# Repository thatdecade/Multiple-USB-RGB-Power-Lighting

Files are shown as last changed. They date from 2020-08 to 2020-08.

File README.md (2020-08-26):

# Multiple USB RGB Power Lighting
The goal of this project is to set the color of two neopixel rings based on which USB cable is powered.  I plugged the USB cables into my game consoles, so when a console is powered, the shelf llght will have the corresponding color.

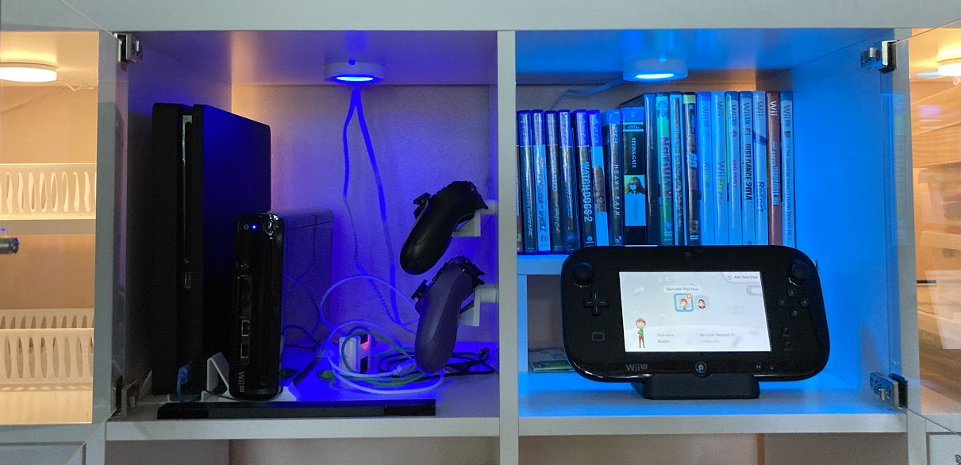
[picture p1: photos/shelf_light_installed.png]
Neopixel Ring Puck Lights


**How it Works**

Plug each USB cable into your separate devices.  The isolation diodes allow the trinket to be powered by any or all of the USB cables.  Periodically, the trinket will read the input pins to determine which USB cable is powered and will play the programmed animation and colors or combination of colors.

The trinket needs pull down resistors to set the idle state of an input pin when a USB cable is not powered or left unattached.

----

**Part List**

* Trinket 5V - <https://amzn.to/3gpQX6z>
* NeoPixel Ring - 16 RGB - <https://amzn.to/34wuUcn>
* Wired Under Cabinet Puck Lights - <https://amzn.to/2YssTdl>
* Backpack PCB - <https://oshpark.com/shared_projects/CATpwF4r>
* Three diodes - <https://octopart.com/search?q=CMF04%28TE12L%2CQ%2CM%29>
* Three 10k resistors - <https://octopart.com/search?q=RC0603FR-0710KL>
* Three USB Cables (dollar store)

The backpack pcb is optional.  You can just as easily wire up the diodes and resistors on a protoboard.  

**Pin Assignments**

Not all pins on the Trinket are equal.  Be sure to read Adafruit's help pages <https://learn.adafruit.com/introducing-trinket/pinouts>  Pins 3 and 4 should not be used as inputs and will conflict with talking to a PC for programming.

* GPIO #0 - Red Input, Attach to +5V wire from the first USB cable
* GPIO #1 - Blue Input, Attach to +5V wire from the second USB cable
* GPIO #2 - Green Input, Attach to +5V wire from the third USB cable
* GPIO #3 - Neopixel Data
* GPIO #4 - Potentiometer (optional)

I added a quick disconnect to Pin 4 so when I wanted to connect to the PC, I could remove the potentiometer without soldering.

**Assembly**

If you have access to a 3d printer, an enclosure stl is provided.  Thread the cables through the enclosure sides before soldering.

Solder the resistors and diodes to the backpack, then wire into the trinket.  Strip the USB cables and identify the 5V and Ground wires.  Use a multimeter to be sure, but the 5V and Ground wires can also be identified by thickness.  The power wires should be thicker than the data wires.

*There is a RGB LED and three 220 ohm resistors on the backback pcb for debugging, leave them unpopulated.*

Take apart the puck light and remove the PCB.  Recycling the wiring that came with the puck light to wire into your neopixel rings.  Use hot glue or epoxy to add the neopixel ring behind the puck light's diffuser.

**Programming**

Use the arduino ide and adafruit neopixel library and adafruit trinket board package.  Be sure to read Adafruit's help pages for each module.

* <https://learn.adafruit.com/adafruit-arduino-ide-setup/arduino-1-dot-6-x-ide>
* <https://learn.adafruit.com/introducing-trinket/setting-up-with-arduino-ide>
* <https://github.com/adafruit/Adafruit_NeoPixel>

If you followed my pin assignments, you can use the code without modification.  After you get the neopixels to light up and changing based on which USB cable is powered.   You can explore modifying the colors and animations.

**Usage, Testing, and Setting Colors**

After initial programming, when you plug in each of the three USB cables you should see the ring light up red or blue or green.  Combinations are allowed.

If you installed the optional potentiometer, you can change the color selected by a USB cable without reprogramming using a PC.  There are 16 colors preprogrammed to select from.

1. You will need two USB power ports to plug into.  
2. Connect the Micro USB on the trinket so power remains on while the other USBs are unplugged.  Leave this plugged in throughout these steps.
3. Take the USB cable you want to configure and plug it into your power block.  
4. Wait 5 seconds (or just wait for the animation to complete)
5. Rapidly unplug and plug the cable in four times, ending with the USB plugged in.
    1. You must complete this four times, before the spinning animation ends.
    2. If you do it right, the animations will stop and you will see a steady light.  
    3. If you mess up, wait 5 seconds before trying again.
6. Slowly rotate the potentiometer to select the color.
7. Unplug the USB cable to save the color selection.

----

**Additional Notes**

I used the NeoPixel ring and Trinket I listed above because that is what I had extra.  If I were to make one from scratch, I would use the [RGBW Neopixel Rings](https://octopart.com/search?q=adafruit+2854) and [Arduino NANO 33 IoT](https://amzn.to/3lg6Tfj) instead.  So I could use the Puck Light for normal lighting with commands to Alexa to change colors too!  

More Info: <https://blog.arduino.cc/2019/11/12/create-a-voice-controlled-device-with-alexa-and-arduino-iot-cloud-in-7-minutes/>

_We are a participant in the Amazon Services LLC Associates Program, an affiliate advertising program designed to provide a means for us to earn fees by linking to Amazon.com and affiliated sites._

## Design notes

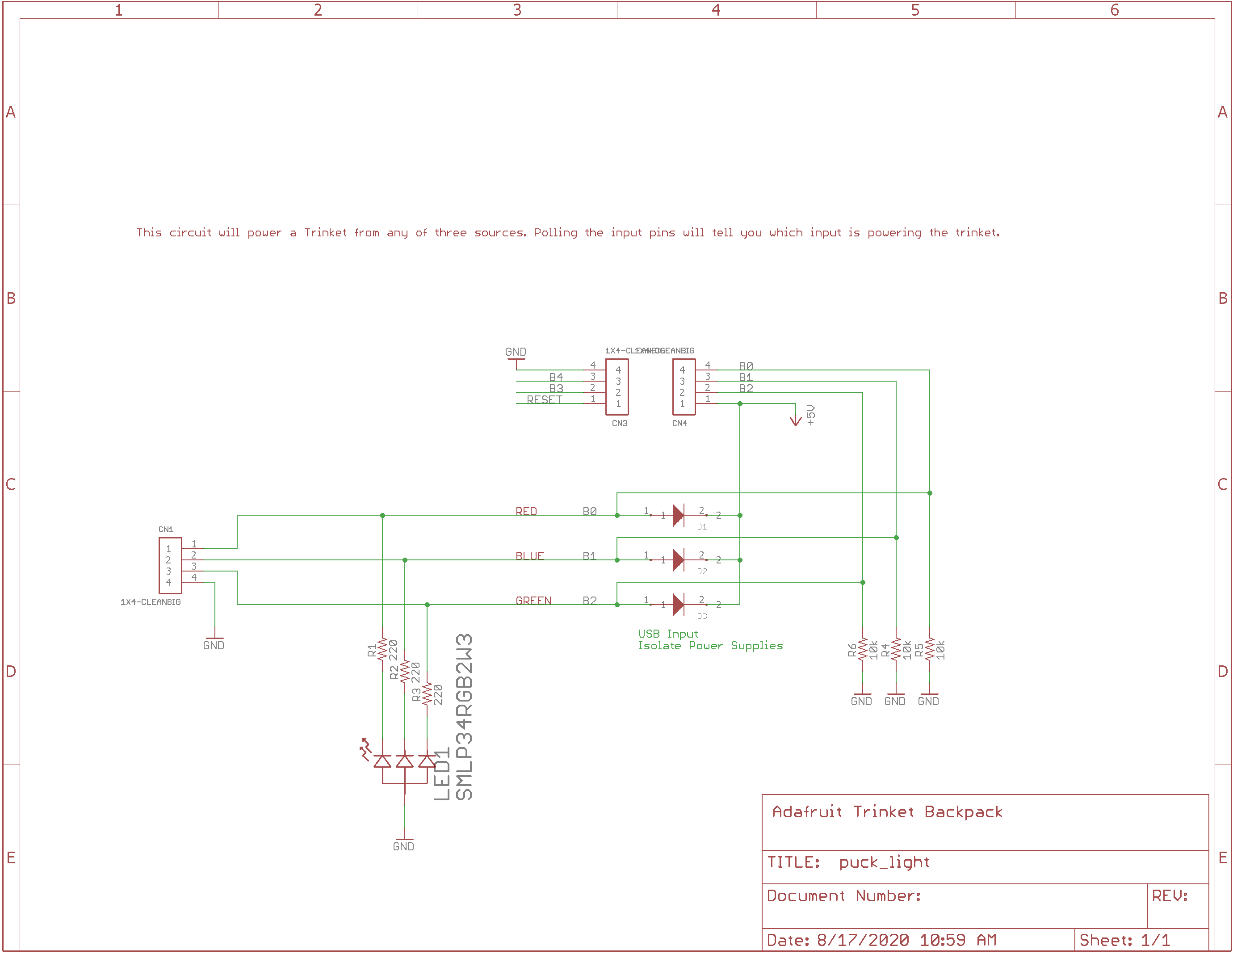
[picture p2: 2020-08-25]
pcb/schematic.png

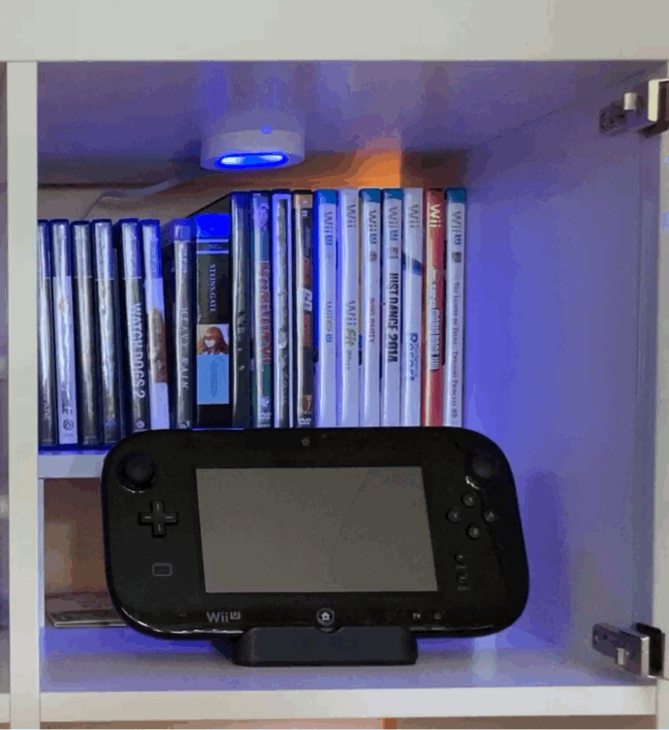
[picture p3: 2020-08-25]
photos/shelf_light_animation.gif

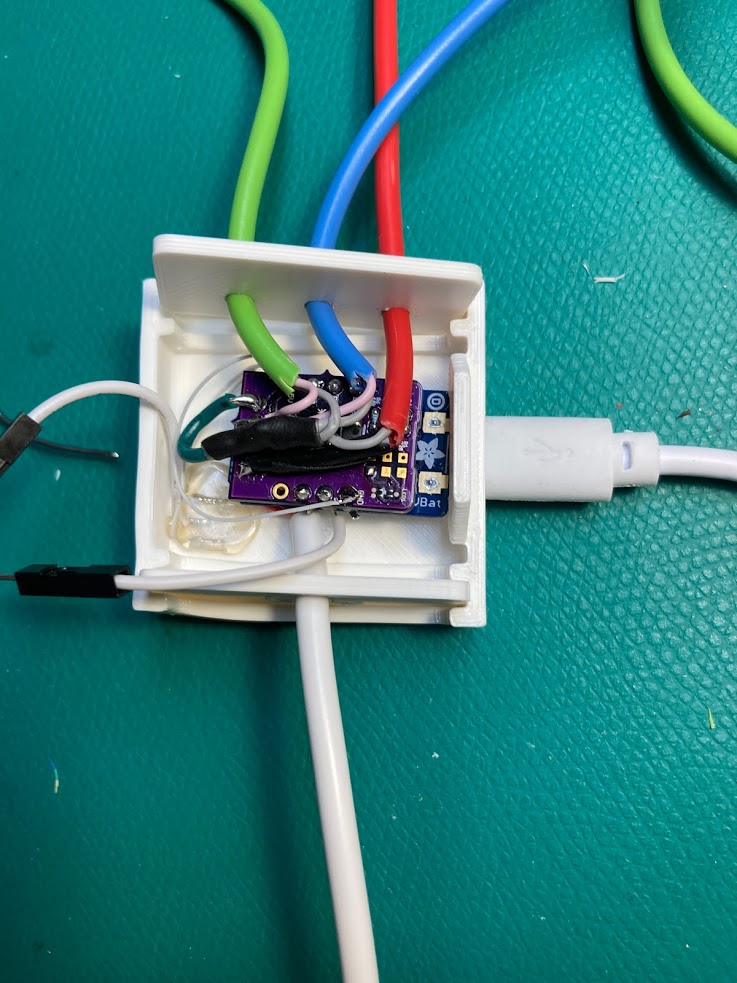
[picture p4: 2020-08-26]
photos/inside_enclosure.jpg

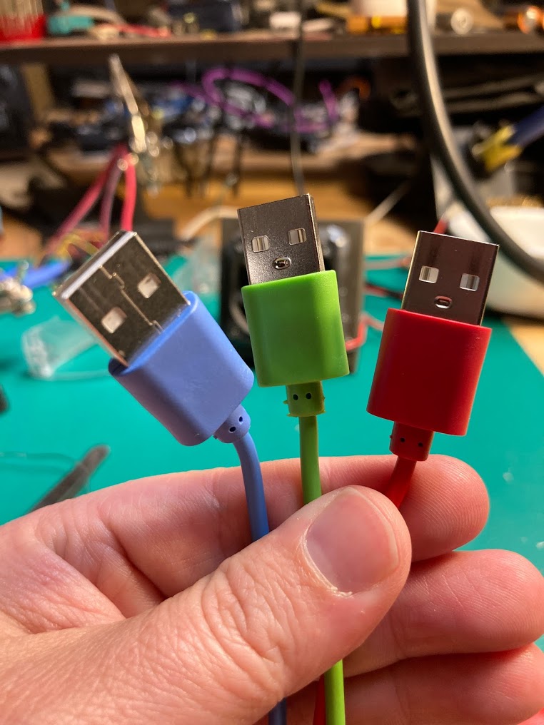
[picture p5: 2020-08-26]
photos/colored_usb_cables.jpg

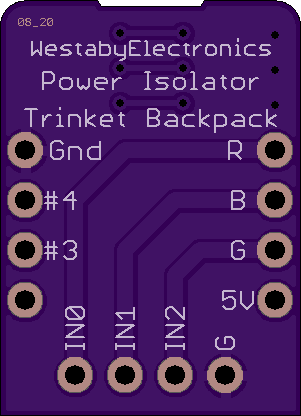
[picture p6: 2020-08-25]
photos/PCB_Front.png

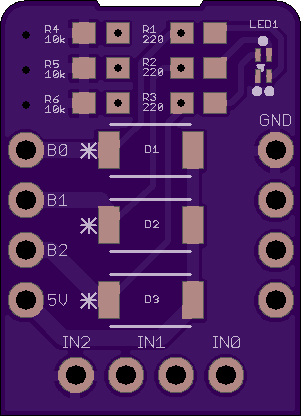
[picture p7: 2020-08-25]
photos/PCB_Back.png

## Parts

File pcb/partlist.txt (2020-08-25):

Partlist

EAGLE Version 7.7.0 Copyright (c) 1988-2016 CadSoft

Assembly variant: 

Part     Value            Package          Library            Position (inch)       Orientation

D1       CMF04(TE12L,Q,M) M-FLAT_TOS       CMF04(TE12L,Q)     (0.3 0.55)            MR0
D2       CMF04(TE12L,Q,M) M-FLAT_TOS       CMF04(TE12L,Q)     (0.3 0.4)             MR0
D3       CMF04(TE12L,Q,M) M-FLAT_TOS       CMF04(TE12L,Q)     (0.3 0.25)            MR0
LED1     SMLP34RGB2W3     LED_SML-P24M_ROM SMLP34RGB2W3A      (0.075 0.72)          MR90
R1       220              0603             SparkFun-Resistors (0.205 0.785)         MR180
R2       220              0603             SparkFun-Resistors (0.205 0.715)         MR180
R3       220              0603             SparkFun-Resistors (0.205 0.645)         MR180
R4       10k              0603             SparkFun-Resistors (0.4 0.715)           MR0
R5       10k              0603             SparkFun-Resistors (0.4 0.785)           MR0
R6       10k              0603             SparkFun-Resistors (0.4 0.645)           MR0

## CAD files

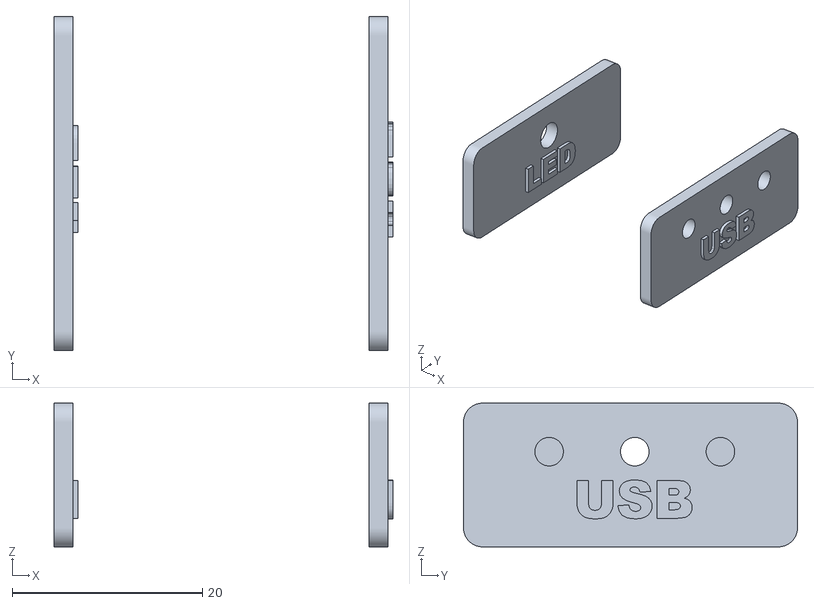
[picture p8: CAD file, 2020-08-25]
3d_parts/LED_USB_Box_Sides.stl
35.6 x 35.1 x 15.1

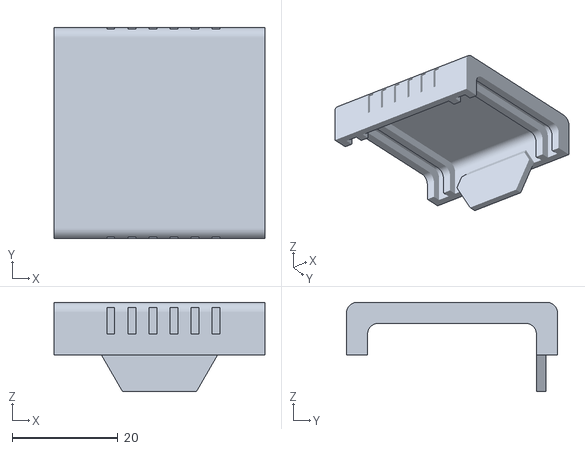
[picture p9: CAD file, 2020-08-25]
3d_parts/LED_USB_Box_Top.stl
40.0 x 40.0 x 16.9

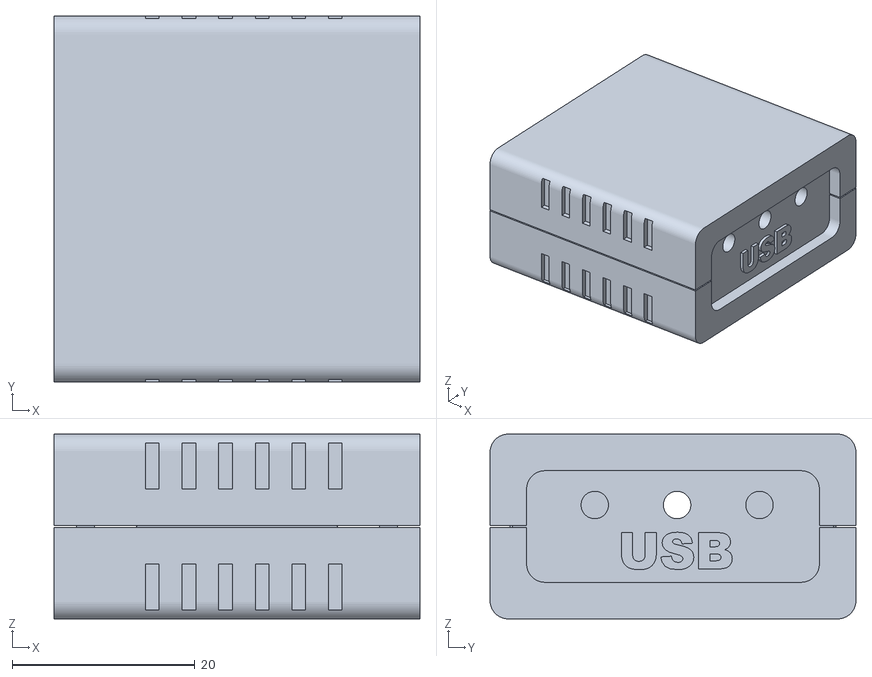
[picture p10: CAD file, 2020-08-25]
3d_parts/LED_USB_Box.stl
40.0 x 40.0 x 20.2

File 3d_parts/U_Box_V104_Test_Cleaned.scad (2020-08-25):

/*//////////////////////////////////////////////////////////////////
              -    FB Aka Heartman/Hearty 2016     -                   
              -   http://heartygfx.blogspot.com    -                  
              -       OpenScad Parametric Box      -                     
              -         CC BY-NC 3.0 License       -                      
////////////////////////////////////////////////////////////////////                                                                                                             
12/02/2016 - Fixed minor bug 
28/02/2016 - Added holes ventilation option                    
09/03/2016 - Added PCB feet support, fixed the shell artefact on export mode. 

*/////////////////////////// - Info - //////////////////////////////

// All coordinates are starting as integrated circuit pins.
// From the top view :

//   CoordD           <---       CoordC
//                                 ^
//                                 ^
//                                 ^
//   CoordA           --->       CoordB


////////////////////////////////////////////////////////////////////


////////// - Paramètres de la boite - Box parameters - /////////////

/* [Box dimensions] */
// - Longueur - Length  
  Length        = 40;       
// - Largeur - Width
  Width         = 40;                     
// - Hauteur - Height  
  Height        = 20;  
// - Epaisseur - Wall thickness  
  Thick         = 2;//[2:5]  
  
/* [Box options] */
// - Diamètre Coin arrondi - Filet diameter  
  Filet         = 2;//[0.1:12] 
// - lissage de l'arrondi - Filet smoothness  
  Resolution    = 50;//[1:100] 
// - Tolérance - Tolerance (Panel/rails gap)
  m             = 0.9;
// Pieds PCB - PCB feet (x4) 
  PCBFeet       = 0;// [0:No, 1:Yes]
// - Decorations to ventilation holes
  Vent          = 0;// [0:No, 1:Yes]
// - Decoration-Holes width (in mm)
  Vent_width    = 1.5;   


  
/* [PCB_Feet] */
//All dimensions are from the center foot axis

// - Coin bas gauche - Low left corner X position
PCBPosX         = 7;
// - Coin bas gauche - Low left corner Y position
PCBPosY         = 6;
// - Longueur PCB - PCB Length
PCBLength       = 70;
// - Largeur PCB - PCB Width
PCBWidth        = 50;
// - Heuteur pied - Feet height
FootHeight      = 10;
// - Diamètre pied - Foot diameter
FootDia         = 8;
// - Diamètre trou - Hole diameter
FootHole        = 3;  
  

/* [STL element to export] */
//Coque haut - Top shell
TShell          = 1;// [0:No, 1:Yes]
//Coque bas- Bottom shell
BShell          = 1;// [0:No, 1:Yes]
//Panneau avant - Front panel
FPanL           = 1;// [0:No, 1:Yes]
//Panneau arrière - Back panel  
BPanL           = 1;// [0:No, 1:Yes]


  
/* [Hidden] */
// - Couleur coque - Shell color  
Couleur1        = "Orange";       
// - Couleur panneaux - Panels color    
Couleur2        = "OrangeRed";    
// Thick X 2 - making decorations thicker if it is a vent to make sure they go through shell
Dec_Thick       = Vent ? Thick*2 : Thick; 
// - Depth decoration
Dec_size        = Vent ? Thick*2 : 0.8;





/////////// - Boitier générique bord arrondis - Generic rounded box - //////////

module RoundBox($a=Length, $b=Width, $c=Height){// Cube bords arrondis
                    $fn=Resolution;            
                    translate([0,Filet,Filet]){  
                    minkowski (){                                              
                        cube ([$a-(Length/2),$b-(2*Filet),$c-(2*Filet)], center = false);
                        rotate([0,90,0]){    
                        cylinder(r=Filet,h=Length/2, center = false);
                            } 
                        }
                    }
                }// End of RoundBox Module

      
////////////////////////////////// - Module Coque/Shell - //////////////////////////////////         

module Coque(){//Coque - Shell  
    Thick = Thick*2;  
    difference(){    
        difference(){//sides decoration
            union(){    
                     difference() {//soustraction de la forme centrale - Substraction Fileted box
                      
                        difference(){//soustraction cube median - Median cube slicer
                            union() {//union               
                            difference(){//Coque    
                                RoundBox();
                                translate([Thick/2,Thick/2,Thick/2]){     
                                        RoundBox($a=Length-Thick, $b=Width-Thick, $c=Height-Thick);
                                        }
                                        }//Fin diff Coque                            
                                difference(){//largeur Rails        
                                     translate([Thick+m,Thick/2,Thick/2]){// Rails
                                          RoundBox($a=Length-((2*Thick)+(2*m)), $b=Width-Thick, $c=Height-(Thick*2));
                                                          }//fin Rails
                                     translate([((Thick+m/2)*1.55),Thick/2,Thick/2+0.1]){ // +0.1 added to avoid the artefact
                                          RoundBox($a=Length-((Thick*3)+2*m), $b=Width-Thick, $c=Height-Thick);
                                                    }           
                                                }//Fin largeur Rails
                                    }//Fin union                                   
                               translate([-Thick,-Thick,Height/2]){// Cube à soustraire
                                    cube ([Length+100, Width+100, Height], center=false);
                                            }                                            
                                      }//fin soustraction cube median - End Median cube slicer
                               translate([-Thick/2,Thick,Thick]){// Forme de soustraction centrale 
                                    RoundBox($a=Length+Thick, $b=Width-Thick*2, $c=Height-Thick);       
                                    }                          
                                }                                          


                difference(){// wall fixation box legs
                    union(){
                        translate([3*Thick +5,Thick,Height/2]){
                            rotate([90,0,0]){
                                    $fn=6;
                                    cylinder(d=16,Thick/2);
                                    }   
                            }
                            
                       translate([Length-((3*Thick)+5),Thick,Height/2]){
                            rotate([90,0,0]){
                                    $fn=6;
                                    cylinder(d=16,Thick/2);
                                    }   
                            }

                        }
                            translate([4,Thick+Filet,Height/2-57]){   
                             rotate([45,0,0]){
                                   cube([Length,40,40]);    
                                  }
                           }
                           translate([0,-(Thick*1.46),Height/2]){
                                cube([Length,Thick*2,10]);
                           }
                    } //Fin fixation box legs
            }

        union(){// outbox sides decorations
            
            for(i=[0:Thick:Length/4]){

                // Ventilation holes part code submitted by Ettie - Thanks ;) 
                    translate([10+i,-Dec_Thick+Dec_size,1]){
                    cube([Vent_width,Dec_Thick,Height/4]);
                    }
                    translate([(Length-10) - i,-Dec_Thick+Dec_size,1]){
                    cube([Vent_width,Dec_Thick,Height/4]);
                    }
                    translate([(Length-10) - i,Width-Dec_size,1]){
                    cube([Vent_width,Dec_Thick,Height/4]);
                    }
                    translate([10+i,Width-Dec_size,1]){
                    cube([Vent_width,Dec_Thick,Height/4]);
                    }
  
                
                    }// fin de for
               // }
                }//fin union decoration
            }//fin difference decoration
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

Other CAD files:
3d_parts/LED_USB_Box_Bottom.stl

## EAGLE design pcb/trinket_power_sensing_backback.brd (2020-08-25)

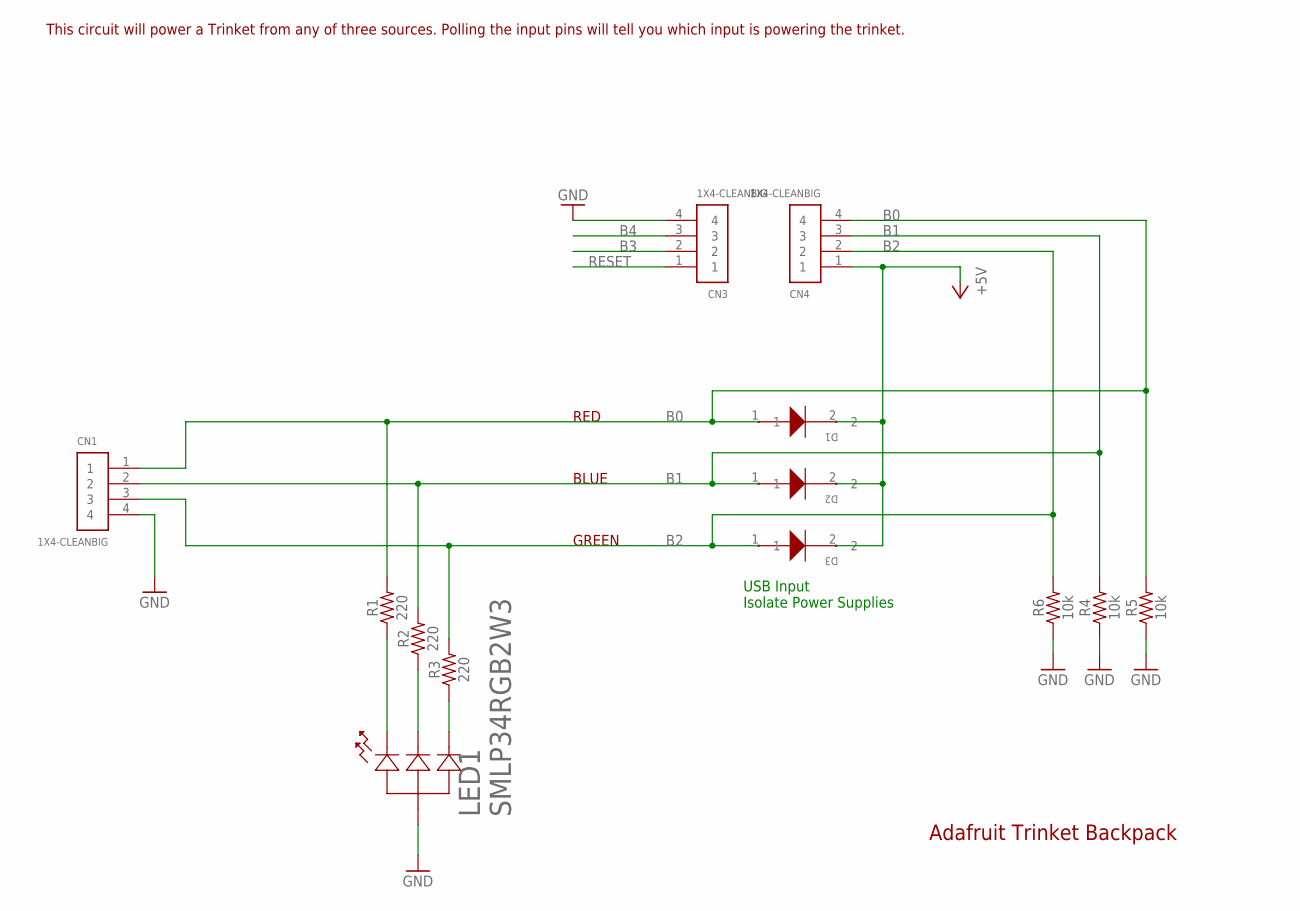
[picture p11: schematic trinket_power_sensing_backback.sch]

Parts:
CN1, CN3, CN4: 1X4-CLEANBIG; 1X04-CLEANBIG
D1, D2, D3: CMF04(TE12L,Q,M); M-FLAT_TOS
LED1: SMLP34RGB2W3; LED_SML-P24M_ROM
R1, R2, R3: 220; 0603
R4, R5, R6: 10k; 0603

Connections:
+5V: CN4.1, D1.2, D2.2, D3.2
B0: CN1.1, CN4.4, D1.1, R1.2, R5.2
B1: CN1.2, CN4.3, D2.1, R2.2, R4.2
B2: CN1.3, CN4.2, D3.1, R3.2, R6.2
B3: CN3.2
B4: CN3.3
GND: CN1.4, CN3.4, LED1.1, R4.1, R5.1, R6.1
unnamed: LED1.2, R1.1
unnamed: LED1.3, R2.1
unnamed: LED1.4, R3.1
RESET: CN3.1

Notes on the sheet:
Adafruit Trinket Backpack
USB Input Isolate Power Supplies
RED
BLUE
GREEN
This circuit will power a Trinket from any of three sources. Polling the input pins will tell you which input is powering the trinket.

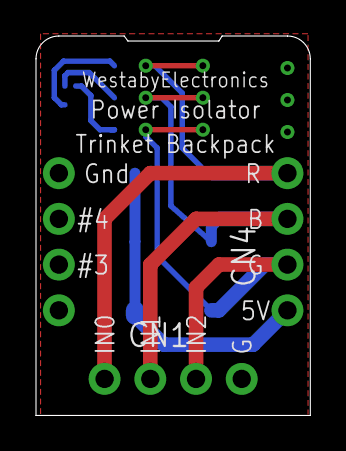
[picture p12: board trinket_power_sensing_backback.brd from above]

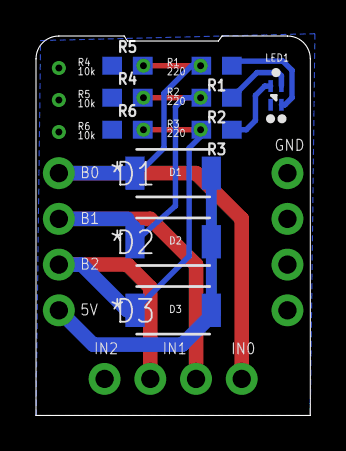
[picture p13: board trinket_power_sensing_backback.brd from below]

Board: 2 copper layers, 15.2 x 21.1 mm, 13 parts (10 on the bottom side), 8 nets.

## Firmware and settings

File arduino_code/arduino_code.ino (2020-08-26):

/* 
 * Trinket Powered Neopixels with Color Selection
 *  
 *  Dustin Westaby
 *  August 2020
 */

#include <Adafruit_NeoPixel.h>
#ifdef __AVR_ATtiny85__ // Trinket, Gemma, etc.
 #include <avr/power.h>
#endif
#include <EEPROM.h>

#define ENABLE_COLOR_KNOB   1        //Set to 0 if you do not plan to use a potentiometer for color selection

#define NUMBER_OF_TOGGLES_TO_ENTER_SETUP 7
#define SETUP_ENTRY_TIMEOUT 5000

#define SPIN_SPEED 60
#define SPIN_DURATION 80

#define SOLID_COLOR_FADE_SPEED 10*15
#define BLANKING_OFFSET 4

#define RED_PIN   0
#define BLUE_PIN  1
#define GREEN_PIN 2
#define NEO_PIN   3
#define POT_PIN   A2

#define NUM_LEDS 32
#define NUM_LEDS_ONE_WHEEL 16

Adafruit_NeoPixel pixels = Adafruit_NeoPixel(NUM_LEDS, NEO_PIN);

uint32_t colorwheel[] =
{
  0xff0000, //0 red
  0x800000, //1 maroon
  0xff4000, //2 orange
  0xffff00, //3 yellow
  0x808000, //4 olive
  0x800080, //5 purple
  0xff00ff, //6 fuschia
  0xffffff, //7 white
  0x000080, //8 navy
  0x0000ff, //9 blue
  0x00ffff, //10 aqua
  0x008080, //11 teal
  0x00ff00, //12 lime
  0x008000, //13 green
};

#define WHEEL_RED_INDEX    0
#define WHEEL_BLUE_INDEX   9
#define WHEEL_GREEN_INDEX  13

uint32_t color1, color2;

uint32_t prevTime;

#define RED_EEPROM_ADDRESS    0
#define GREEN_EEPROM_ADDRESS  4
#define BLUE_EEPROM_ADDRESS   8

uint32_t user_color[3];

#define USER_RED_INDEX    0
#define USER_GREEN_INDEX  1
#define USER_BLUE_INDEX   2

typedef enum
{
  START = 0,
  SPINNING,
  FADING,
  IDLE_MODE,
  SETUP_MODE_RED,
  SETUP_MODE_BLUE,
  SETUP_MODE_GREEN,
} mode_e;

mode_e system_mode = START;

void setup() 
{
#ifdef __AVR_ATtiny85__ // Trinket, Gemma, etc.
  if(F_CPU == 16000000) clock_prescale_set(clock_div_1);
#endif
  pixels.begin();
  pixels.setBrightness(255);

  pinMode(RED_PIN,   INPUT);
  pinMode(BLUE_PIN,  INPUT);
  pinMode(GREEN_PIN, INPUT);
  pinMode(POT_PIN,   INPUT);

  //set starup colors
  user_color[USER_RED_INDEX]   = get_color_from_index(WHEEL_RED_INDEX);
  user_color[USER_GREEN_INDEX] = get_color_from_index(WHEEL_GREEN_INDEX);
  user_color[USER_BLUE_INDEX]  = get_color_from_index(WHEEL_BLUE_INDEX);
  color1  = user_color[USER_BLUE_INDEX];
  color2  = user_color[USER_BLUE_INDEX];

  read_colors_from_eeprom();
  
  prevTime = millis();

  system_mode = START;
}

void loop() {

  check_for_setup_entry();

  check_for_input_changes();

  update_state_machine();

  draw_animation();
}

void check_for_setup_entry()
{
  static uint32_t previous_user_interaction = 0;
  static uint8_t user_toggle_counter = 0;
  static uint8_t previous_user_value = 0;
  static uint8_t current_user_value = 0;

  current_user_value = (digitalRead(GREEN_PIN) << 1) + (digitalRead(RED_PIN) << 0) + (digitalRead(BLUE_PIN) << 2);

  if(current_user_value != previous_user_value)
  {
    previous_user_value = current_user_value;
    user_toggle_counter++;
    previous_user_interaction = millis();
  }

  if(user_toggle_counter > NUMBER_OF_TOGGLES_TO_ENTER_SETUP)
  {
    user_toggle_counter = 0;

    if(current_user_value == 1)
    {
      setup_mode(RED_PIN, USER_RED_INDEX, RED_EEPROM_ADDRESS);
    }
    
    if(current_user_value == 2)
    {
      setup_mode(GREEN_PIN, USER_GREEN_INDEX, GREEN_EEPROM_ADDRESS);
    }
    
    if(current_user_value == 4)
    {
      setup_mode(BLUE_PIN, USER_BLUE_INDEX, BLUE_EEPROM_ADDRESS);
    }
  }

  if((previous_user_interaction + SETUP_ENTRY_TIMEOUT) < millis())
  {
    user_toggle_counter = 0;
    previous_user_interaction = millis();
  }
  
}

void setup_mode(int pin, uint8_t index, uint8_t eeprom_address)
{
  int analog = 0;
  uint8_t i;
 
  //continue to read pot until USB is pulled
  while(digitalRead(pin) == HIGH)
  {
    //read POT set colors
    analog = analogRead(POT_PIN);

    pixels.setBrightness(45);
    
    for(i=0; i<NUM_LEDS; i++) 
    {
      pixels.setPixelColor(i, lookup_color_from_analog(analog));
    }
    pixels.show();
    delay(500);
  }

  //write to eeprom
  user_color[index] = lookup_color_from_analog(analog);
  EEPROM.write(eeprom_address, map(analog, 0, 1024, 0, ( sizeof( colorwheel ) / sizeof( uint32_t ) ) ));
}

void read_colors_from_eeprom()
{
  if(ENABLE_COLOR_KNOB)
  {
    user_color[USER_RED_INDEX]   = EEPROM.read(RED_EEPROM_ADDRESS);
    user_color[USER_GREEN_INDEX] = EEPROM.read(GREEN_EEPROM_ADDRESS);
    user_color[USER_BLUE_INDEX]  = EEPROM.read(BLUE_EEPROM_ADDRESS);
  
    if(user_color[USER_RED_INDEX] > ( sizeof( colorwheel ) / sizeof( uint32_t ) ))
    {
      user_color[USER_RED_INDEX] = WHEEL_RED_INDEX;
      
      EEPROM.write(RED_EEPROM_ADDRESS, WHEEL_RED_INDEX);
    }
    if(user_color[USER_GREEN_INDEX] > ( sizeof( colorwheel ) / sizeof( uint32_t ) ))
    {
      user_color[USER_GREEN_INDEX] = WHEEL_GREEN_INDEX;
      
      EEPROM.write(GREEN_EEPROM_ADDRESS, WHEEL_GREEN_INDEX);
    }
    if(user_color[USER_BLUE_INDEX] > ( sizeof( colorwheel ) / sizeof( uint32_t ) ))
    {
      user_color[USER_BLUE_INDEX] = WHEEL_BLUE_INDEX;
      
      EEPROM.write(BLUE_EEPROM_ADDRESS, WHEEL_BLUE_INDEX);
    }

    user_color[USER_RED_INDEX]   = get_color_from_index(user_color[USER_RED_INDEX]);
    user_color[USER_GREEN_INDEX] = get_color_from_index(user_color[USER_GREEN_INDEX]);
    user_color[USER_BLUE_INDEX]  = get_color_from_index(user_color[USER_BLUE_INDEX]);
  }
}

void write_colors_from_eeprom(uint8_t red_idx, uint8_t green_idx, uint8_t blue_idx)
{
    EEPROM.write(RED_EEPROM_ADDRESS,   red_idx);
    EEPROM.write(GREEN_EEPROM_ADDRESS, green_idx);
    EEPROM.write(BLUE_EEPROM_ADDRESS,  blue_idx);
}

uint32_t get_color_from_index(uint8_t index)
{
  //perform lookup in a function to reduce program size
  return colorwheel[index];
}

uint32_t lookup_color_from_analog(int analog)
{
  return get_color_from_index(map(analog, 0, 1024, 0, ( sizeof( colorwheel ) / sizeof( uint32_t ) ) ));
}

void update_state_machine()
{
  static uint32_t previous_color1 = 0;
  static uint32_t previous_color2 = 0;
  
  //reset animations
  if( (color1 != previous_color1) ||
      (color2 != previous_color2))
  {
    previous_color1 = color1;
    previous_color2 = color2;

    system_mode = SPINNING;
  }
}

void draw_animation()
{
  if(system_mode == SPINNING)
  {
    animate_spin();
  }
  else if (system_mode == FADING)
  {
    solid_color_fade_down();
  }
}

void check_for_input_changes()
{
  //read inputs and set color

  //NONE
  
  if((digitalRead(GREEN_PIN) == LOW) && 
     (digitalRead(RED_PIN) == LOW) && 
     (digitalRead(BLUE_PIN) == LOW))
  {
    color1 = 0x0;
    color2 = 0x0;
  }
  
  //SINGLES
  
  if((digitalRead(GREEN_PIN) == HIGH) && 
     (digitalRead(RED_PIN) == LOW) && 
     (digitalRead(BLUE_PIN) == LOW))
  {
    color1 = user_color[USER_GREEN_INDEX];
    color2 = user_color[USER_GREEN_INDEX];
  }
  if((digitalRead(GREEN_PIN) == LOW) && 
     (digitalRead(RED_PIN) == HIGH) && 
     (digitalRead(BLUE_PIN) == LOW))
  {
    color1 = user_color[USER_RED_INDEX];
    color2 = user_color[USER_RED_INDEX];
  }
  if((digitalRead(GREEN_PIN) == LOW) && 
     (digitalRead(RED_PIN) == LOW) && 
     (digitalRead(BLUE_PIN) == HIGH))
  {
    color1 = user_color[USER_BLUE_INDEX];
    color2 = user_color[USER_BLUE_INDEX];
  }

  //DOUBLES
  
  if((digitalRead(GREEN_PIN) == HIGH) && 
     (digitalRead(RED_PIN) == HIGH) && 
     (digitalRead(BLUE_PIN) == LOW))
  {
    color1 = user_color[USER_GREEN_INDEX];
    color2 = user_color[USER_RED_INDEX];
  }
  if((digitalRead(GREEN_PIN) == HIGH) && 
     (digitalRead(RED_PIN) == LOW) && 
     (digitalRead(BLUE_PIN) == HIGH))
  {
    color1 = user_color[USER_BLUE_INDEX];
    color2 = user_color[USER_GREEN_INDEX];
  }
  if((digitalRead(RED_PIN) == HIGH) && 
     (digitalRead(BLUE_PIN) == HIGH))
  {
    //DOUBLES and TRIPLES, Favor blue RED, even if green is also ON
    color1 = user_color[USER_BLUE_INDEX];
    color2 = user_color[USER_RED_INDEX];
  }
}

void animate_spin()
{
  static uint8_t i = 0;
  static uint8_t j = 0;
  static int offset = 0;
  static mode_e previous_system_mode = START;

  if(previous_system_mode != system_mode)
  {
    i = 0;
    j = 0;
    previous_system_mode = system_mode;
  }

  if((system_mode == SPINNING) && ((prevTime + SPIN_SPEED) < millis()))
  {
    prevTime = millis();
    
    // Spinny wheels (4 LEDs on at a time)
  
    pixels.setBrightness(254);
    
    for(i=0; i<NUM_LEDS_ONE_WHEEL; i++) 
    {
      uint32_t c = 0;
      uint32_t d = 0;
      if(((offset + i) & 7) < 2)
      {
        c = color1; // 4 pixels on...
        d = color2; // 4 pixels on...
      }
      pixels.setPixelColor(   i, c);
      pixels.setPixelColor(NUM_LEDS-1-i, d);
    }
    offset++;
    pixels.show();

    j++;
    if(j >= SPIN_DURATION)
    {
      system_mode = FADING;
      previous_system_mode = system_mode;
    }
  }
}

void solid_color_fade_down()
{
  static uint8_t i = 0;
  static uint8_t j = 0;
  static mode_e previous_system_mode = START;
  static uint32_t previous_primary_color = 0xff0000;
  
  if(previous_system_mode != system_mode)
  {
    i = 0;
    j = 0;
    previous_system_mode = system_mode;
  }

  if((system_mode == FADING) && ((prevTime + SOLID_COLOR_FADE_SPEED) < millis()))
  {
    prevTime = millis();
    
    //set to solid color, while also dimming gradually.

    pixels.setBrightness(map(i,0,16,254,45));

    pixels.setPixelColor(           i, color1);
    pixels.setPixelColor(NUM_LEDS-1-i, color2);

    if((i+BLANKING_OFFSET)<16)
    {
      pixels.setPixelColor(           (i+BLANKING_OFFSET), 0);
      pixels.setPixelColor(NUM_LEDS-1-(i+BLANKING_OFFSET), 0);
    }
    pixels.show();

    i++;
    if(i >= 16)
    {
      system_mode = IDLE_MODE;
      previous_system_mode = system_mode;
    }
  }
}

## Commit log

2020-08-25 3d enclosure
    [LED_USB_Box.stl, LED_USB_Box_Bottom.stl, LED_USB_Box_Sides.stl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]
2020-08-26 Fixed bug in fade down animation
    [arduino_code.ino]
2020-08-26 Assembly photos

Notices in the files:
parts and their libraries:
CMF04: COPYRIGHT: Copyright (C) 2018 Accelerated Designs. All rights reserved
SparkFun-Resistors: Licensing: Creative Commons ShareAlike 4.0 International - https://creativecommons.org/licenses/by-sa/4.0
